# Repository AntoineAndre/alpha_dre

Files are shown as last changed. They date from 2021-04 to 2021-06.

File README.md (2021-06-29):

# &#945;. Dré

__Or "How to fit an ISO layout in a 40% keyboard ?"__

## Table of contents
- [Presentation](#Presentation)
- [Layout](#Layout)
- [Case](#Case), more details [here](case/case_doc.md)
- [PCB](#PCB), more details [here](pcb/pcb_doc.md)
- [Parts](#Parts)
- [Results](#Results)
- [Renders](#Renders), more details [here](renders/renders_doc.md)

## Presentation

This project started as a need to find a **new mechanical keyboard with a french ISO layout support**. It also aims to keep a minimalist design that we can find on most 40% keyboards. It will therefore include all the 3D CAD files and various pcb related files to conduct the project along with a documentation to build the keyboard.

This keyboard is __Via and Vial compatible__ to give a better user experience (especially when it comes to remapping keys).

pic_both_keeb

__All pictures of this project can be found [here](https://flic.kr/s/aHsmVLZSPn)__ (acrylic case) __and [here](https://flic.kr/s/aHsmVCqc8F)__ (no plate tray mount)

### Layout

The keyboard presents 42 keys that are placed in an ISO layout, and even if the layout seems odd, most of keycaps set will fit this design. With juste 3 layers the keyboard becomes fully usable as shown in the firmware part.

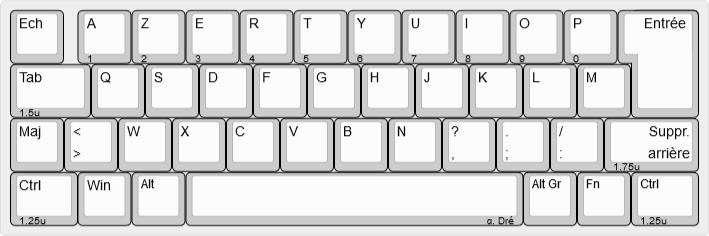
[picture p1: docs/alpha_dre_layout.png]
alpha_dre_layout


### Case

#### 3D printed version

A top mounted case aimed to be 3D printed has been done to complete the build.

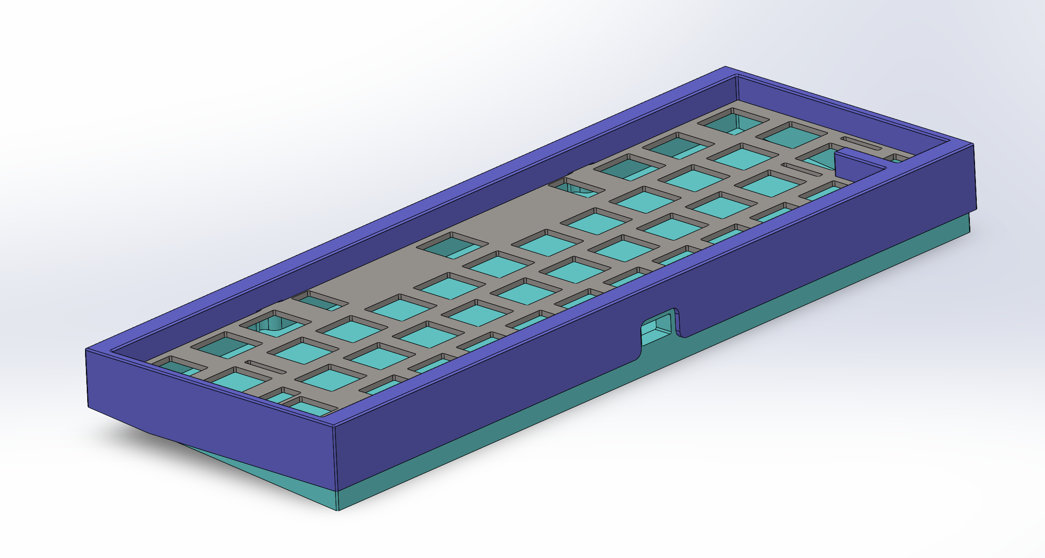
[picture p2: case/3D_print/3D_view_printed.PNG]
case_3D_view


Blueprints are available in dedicated folder, short link to pdf blueprints :
- [global assembly](https://raw.githubusercontent.com/antoineandre/alpha_dre/main/case/3D_print/assembly_blueprint.pdf)
- [top part](https://raw.githubusercontent.com/antoineandre/alpha_dre/main/case/3D_print/bottom_part_blueprint.pdf)
- [bottom part](https://raw.githubusercontent.com/antoineandre/alpha_dre/main/case/3D_print/top_part_blueprint.pdf)

#### Acrylic stack
The case is a *high profile* one (meaning the electronic parts and switches are hidden by the case) and has been designed to be manufactured with only laser cut acrylic plates of various sizes. These plates are fixed with M2 screws (M2x16) and are hidden with rubber bumps on the bottom of the case. This conception leads to a *sandwich mount* keyboard.

In order to give the keyboard a little angle for typing, two different feet have been design to be screwed at the back of the case.

A last option of low profile (barely no case) is available and needs practically no manufacturing. This option leads to a *tray mount* keyboard with no plate (this is the chosen option shown in the beginning of this presentation).

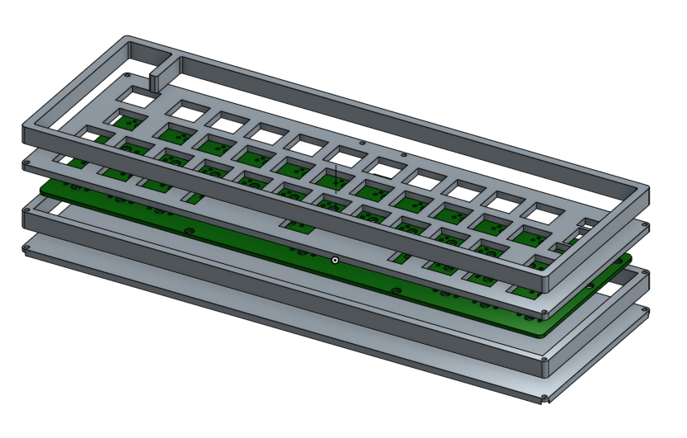
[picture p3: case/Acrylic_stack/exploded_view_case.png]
case_top_view


*Side note on the acrylic case : the design was a bit too lose and the gap between keycaps and top layer of the case can be reduced. Furthermore the plate was designed to host plate mounted stabilizers, but the pcb was designed for pcb mounted stabs...*

### PCB

The pcb has been designed with Kicad software and gerbers files are available in the dedicated folder. This pcb hosts an Atmega32U4-AU for the keyboard control and is (as for other electronic components) soldered in surface. 

pic_pcb

More on the pcb design available in the documentation file.

### Parts

Here is a global list of all parts needed to perform this keyboard build:

- [ ] Laser cut acrylic plates
- [ ] Screws (M2 for sandwich mount and M3 for skeleton mount)
- [ ] SMD components fot the pcb (see the pcb documentation for more details)
- [ ] pcb plate
- [ ] 42 switches
- [ ] 6.25u and 2u stabilizers
- [ ] ISO keycap set
- [ ] Soldering tools
- [ ] Drill and threading tools

<!-- ## Documents

- [case documentation](case/case_doc.md)
- [pcb documentation](pcb/pcb_doc.md)
- [firmware documentation](firmware/alpha_dre/readme.md) -->

### Results

A first prototype with a simple skeleton case made out of plexiglass have been made to validate that the keyboard was responding correctly to the firmware and was usable. More on the cases will be done in the future (notably with the cut acrylic plates for the sandwich mount and with a 3d printed case).

pic_side

Second prototype was made with acrylic sandwich plates (as intended in the original project). Two pictures showing the results of this case can be seen below.

pic_acrylic

pic_acrylic_2

### Renders

A bunch of renders have been made to validate the overall looking of the keyboard.

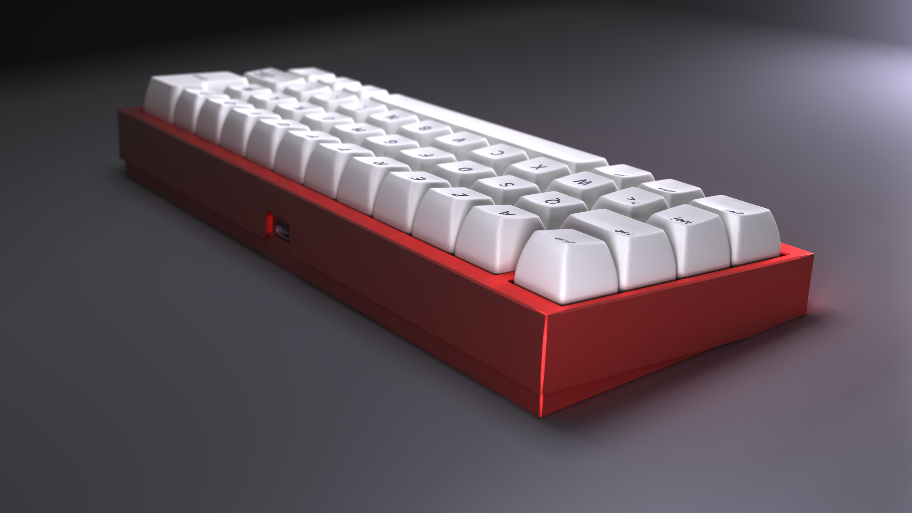
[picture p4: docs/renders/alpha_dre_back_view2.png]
alpha_dre_render


__Complete set of renders__ can be found __[here](docs/renders/renders_doc.md)__

## Aknowledgment

- [Masterzen "Designing a keyboard from scratch" guide](https://www.masterzen.fr/2020/05/03/designing-a-keyboard-part-1/)
- [French mechanical keyboard community](https://github.com/mkbdfr) for their help, feedback and amelioration propositions to make this design as "usable" as possible.

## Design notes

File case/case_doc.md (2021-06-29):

# Case conception and build

## 3D printed case Rev2

Render_view

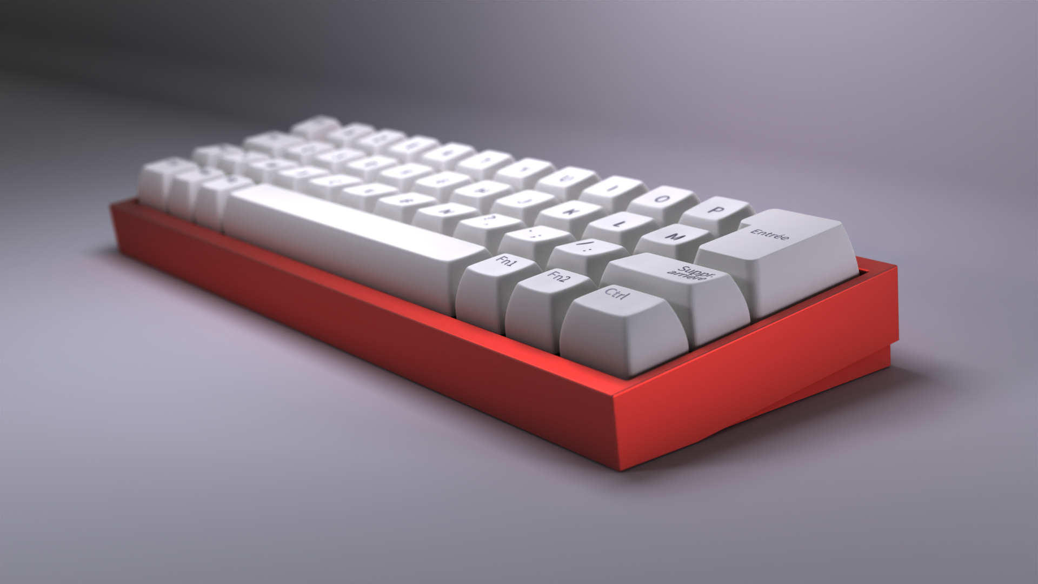
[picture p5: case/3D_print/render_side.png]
Render_view


Blueprints are available here as pdf:
- [assembly scheme](https://github.com/AntoineAndre/alpha_dre/raw/main/case/3D_print/assembly_blueprint.pdf)
- [top part scheme](https://github.com/AntoineAndre/alpha_dre/raw/main/case/3D_print/top_part_blueprint.pdf)
- [top part scheme](https://github.com/AntoineAndre/alpha_dre/raw/main/case/3D_print/bottom_part_blueprint.pdf)

## Acrylic case Rev1

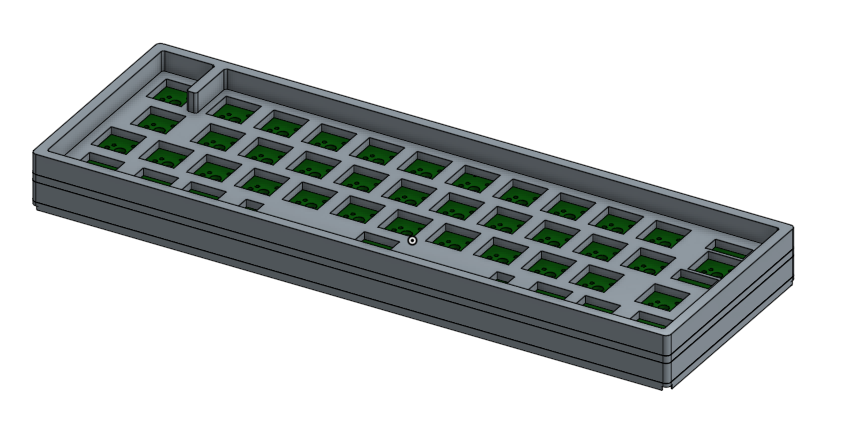
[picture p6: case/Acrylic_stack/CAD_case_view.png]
CAD_view


CAD_view

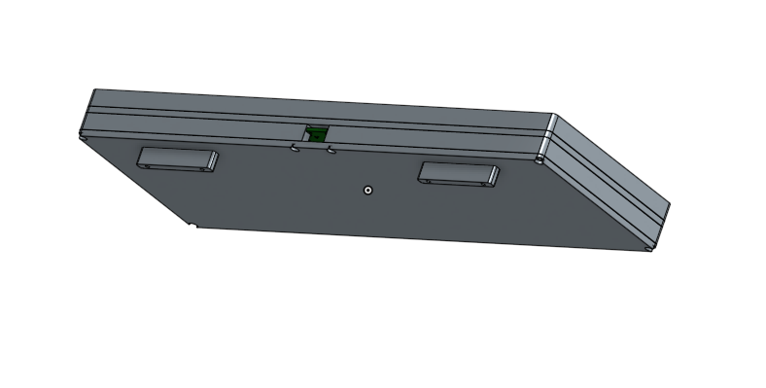
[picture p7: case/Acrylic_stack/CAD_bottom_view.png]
CAD_view


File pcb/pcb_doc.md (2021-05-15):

# Alpha. Dré PCB documentation

## Main design

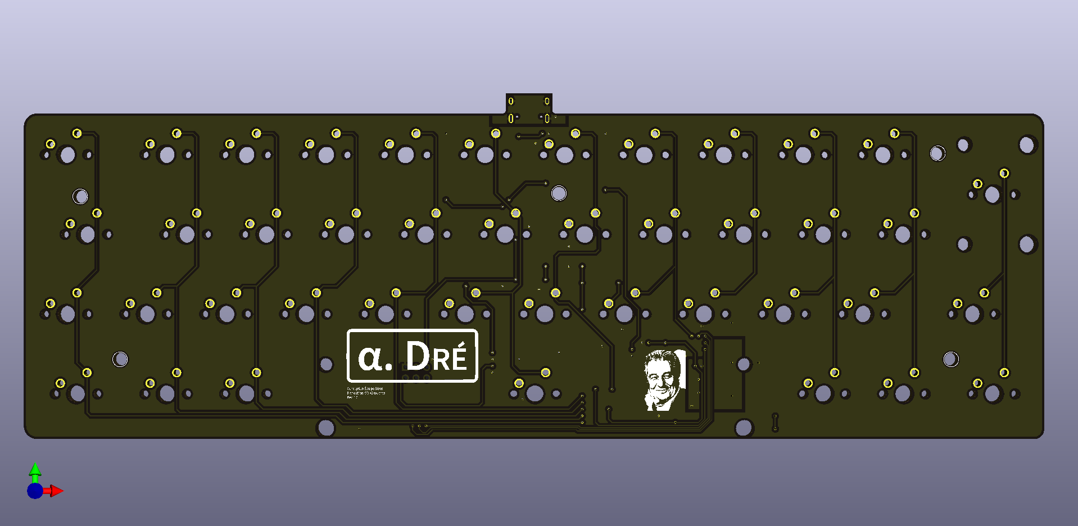
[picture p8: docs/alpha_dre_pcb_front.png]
front view


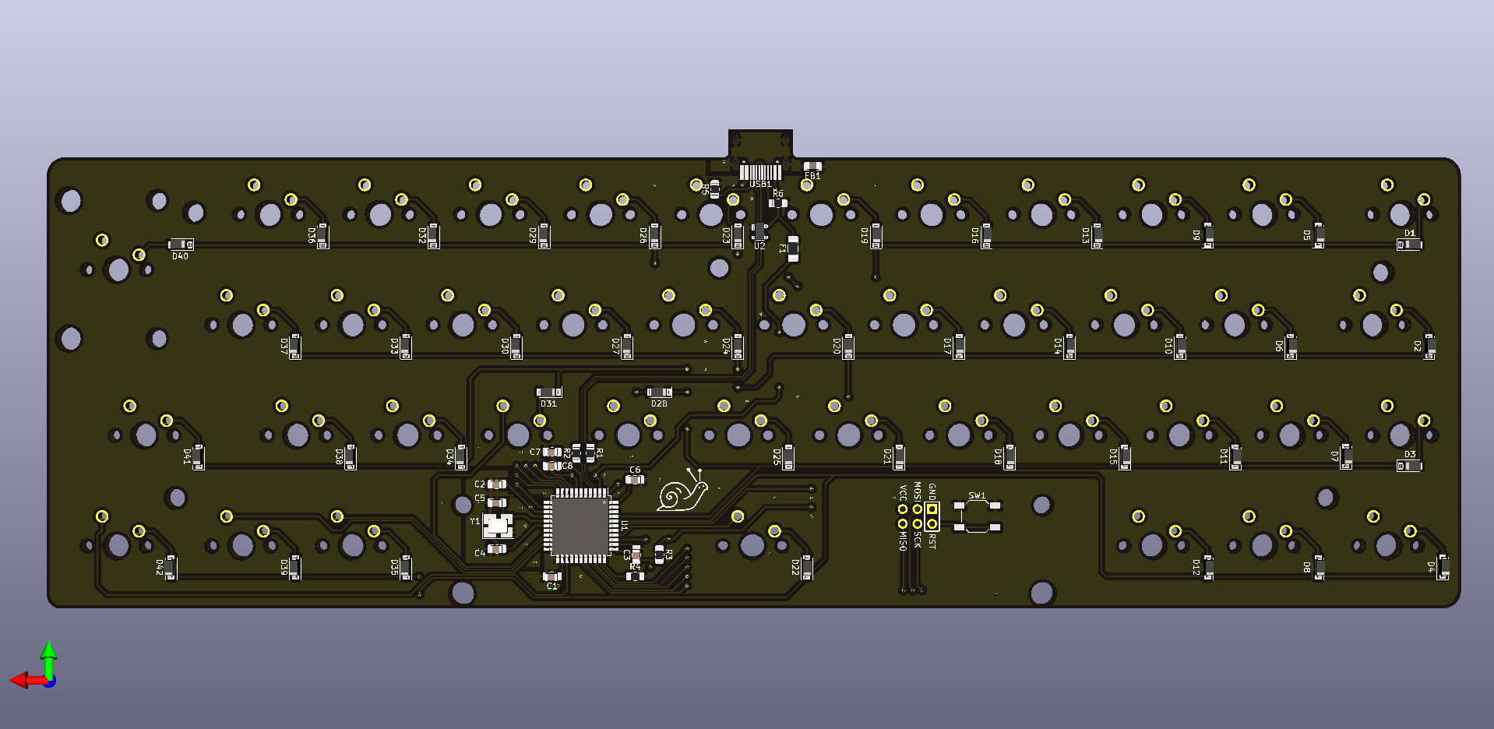
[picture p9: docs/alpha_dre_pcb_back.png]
back view


Even if the design is planed to be sandwich mounted with a stack of acrylic plate, the PCB design offers the possibily to go for a trail mount with dedicated M3 holes (5 evenly spaced on the PCB).

## Part list

The PCB has been designed to be soldered with SMD components and therefore needs a lot of different electronic parts that are listed below:

|Designation|Type |Footprint |Quantity|
|---|---|---|---|
|FB1 |Ferrite bead |805 |1 |
|USB1 |USB connector |HRO-TYPE-C-31-M-12|1 |
|U2 |PRTR5V0U2X |SOT143B |1 |
|SW1 |Reset switch |SKQG |1 |
|R6,R5 |5.1 kOhm resistor|805 |2 |
|R4,R3 |10 kOhm resistor |805 |2 |
|R2,R1 |22 Ohm resistor  |805 |2 |
|C8,C3,C2,C1|100 nF capacitor |805 |4 |
|Y1 |16 MHz crystal |3225 |1 |
|U1 |Atmega 32U4-AU |TQFP-44 |1 |
|F1 |PTC Fuse |1206 |1 |
|C7 |1 uF capacitor |805 |1 |
|C6 |10 uF capacitor  |805 |1 |
|C5,C4 |22 pF capacitor  |805 |2 |
|D1-42 |Diode |SOD-123 |42 |

## Results

After soldering the PCB with all above listed parts the results shooted with a macro lense looks as follow :

pic_pcb

pic_pcb_2

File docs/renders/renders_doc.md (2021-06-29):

# Renders of &#945;. Dré keyboard

alpha_dre_render0

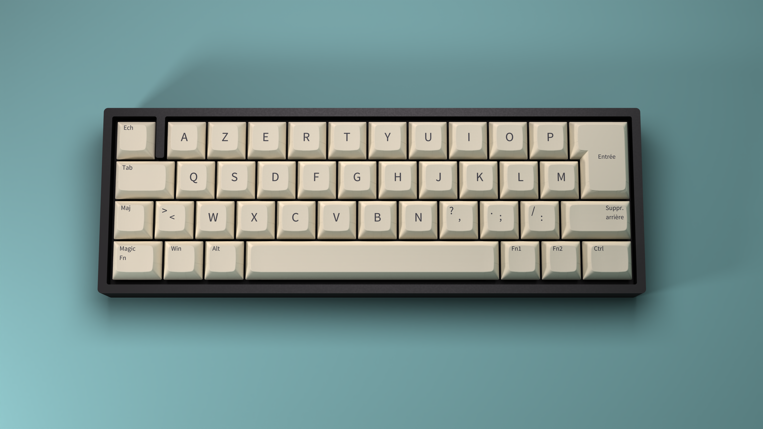
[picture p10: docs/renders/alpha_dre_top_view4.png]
alpha_dre_render1


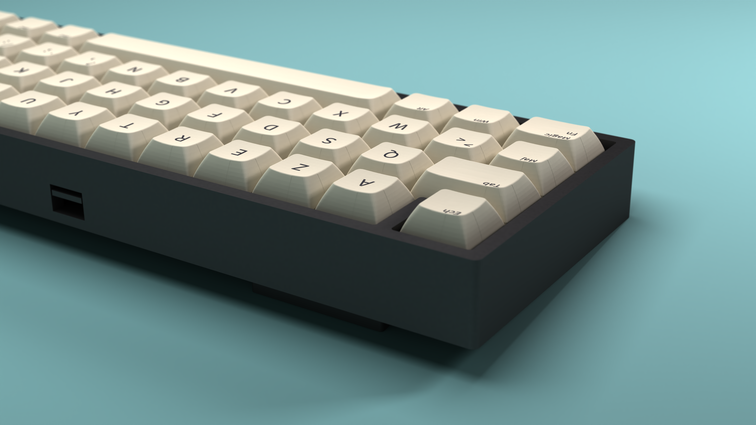
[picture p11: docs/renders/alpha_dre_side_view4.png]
alpha_dre_render2


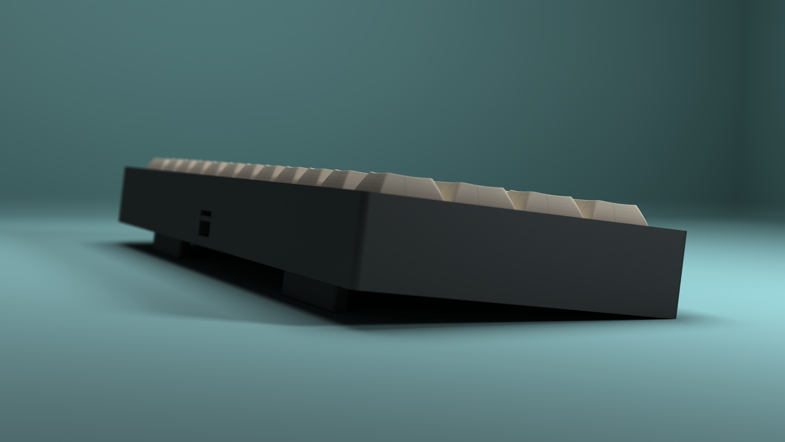
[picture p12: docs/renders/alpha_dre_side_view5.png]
alpha_dre_render3


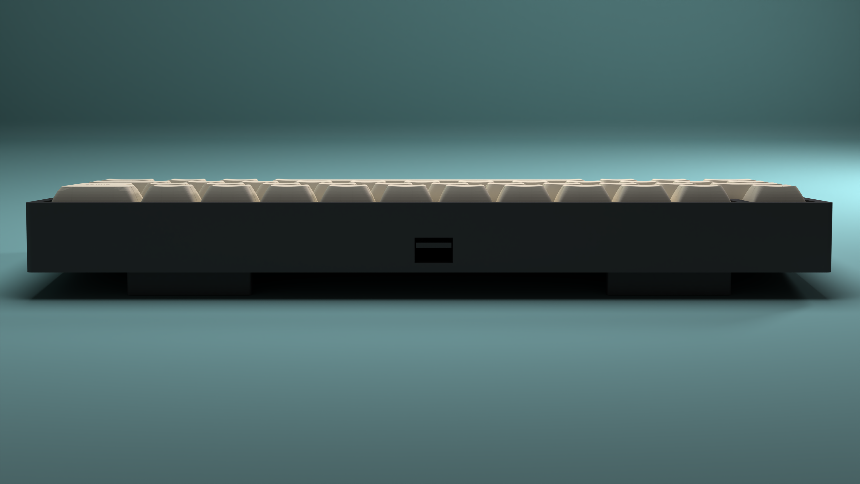
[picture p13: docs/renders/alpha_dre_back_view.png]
alpha_dre_render4


alpha_dre_render5

alpha_dre_render6

alpha_dre_render7

alpha_dre_render8

alpha_dre_render9

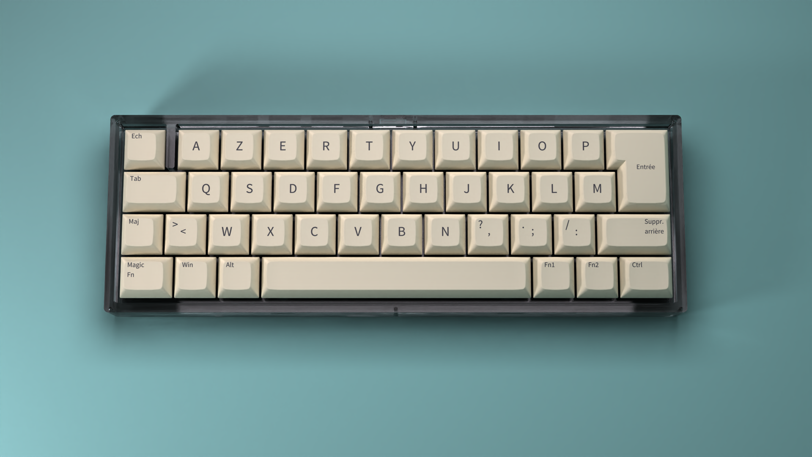
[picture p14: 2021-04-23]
docs/renders/alpha_dre_top_view3.png

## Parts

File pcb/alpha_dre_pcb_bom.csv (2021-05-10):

Id | Designator | Package | Quantity | Designation | Soldered ?
11 | FB1 | L_0805_2012Metric_Pad1.15x1.40mm_HandSolder | 1 | Ferrite_Bead_Small
12 | USB1 | HRO-TYPE-C-31-M-12-HandSoldering | 1 | HRO-TYPE-C-31-M-12
13 | U2 | SOT143B | 1 | PRTR5V0U2X
14 | SW1 | SW_SPST_SKQG_WithStem | 1 | SW_Push
15 | R6,R5 | R_0805_2012Metric_Pad1.20x1.40mm_HandSolder | 2 | 5.1k
16 | R4,R3 | R_0805_2012Metric_Pad1.20x1.40mm_HandSolder | 2 | 10k
17 | R2,R1 | R_0805_2012Metric_Pad1.20x1.40mm_HandSolder | 2 | 22
18 | J1 | Reset_Pretty-Mask | 1 | AVR-ISP-6
19 | C8,C3,C2,C1 | C_0805_2012Metric_Pad1.18x1.45mm_HandSolder | 4 | 0.1uF
20 | Y1 | Crystal_SMD_3225-4Pin_3.2x2.5mm_HandSoldering | 1 | 16MHz
21 | U1 | TQFP-44_10x10mm_P0.8mm | 1 | ATmega32U4-AU
22 | F1 | Fuse_1206_3216Metric_Pad1.42x1.75mm_HandSolder | 1 | 500mA
23 | C7 | C_0805_2012Metric_Pad1.18x1.45mm_HandSolder | 1 | 1uF
24 | C6 | C_0805_2012Metric_Pad1.18x1.45mm_HandSolder | 1 | 10uF
25 | C5,C4 | C_0805_2012Metric_Pad1.18x1.45mm_HandSolder | 2 | 22pF
26 | D42,D41,D40,D39,D38,D37,D36,D35,D34,D33,D32,D31,D30,D29,D28,D27,D26,D25,D24,D23,D22,D21,D20,D19,D18,D17,D16,D15,D14,D13,D12,D11,D10,D9,D8,D7,D6,D5,D4,D3,D2,D1 | D_SOD-123-Pretty | 42 | D_Small

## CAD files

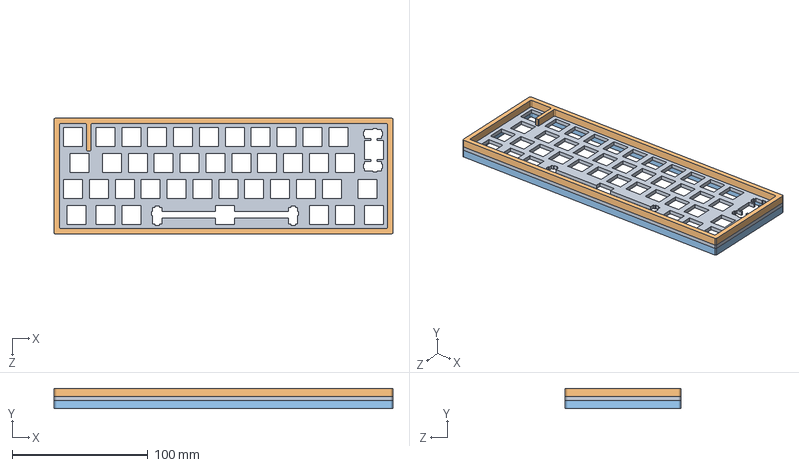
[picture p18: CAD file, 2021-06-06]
case/Rev2/solidworks_project/acry_assembly.SLDASM
249.6 x 15.0 x 85.2 mm
switch_plate
top_plate
mid_plate

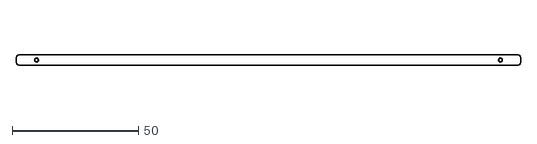
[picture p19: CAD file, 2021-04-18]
case/Acrylic_stack/Acrylic_files/case_foot_option_line.dxf
200.0 x 4.00

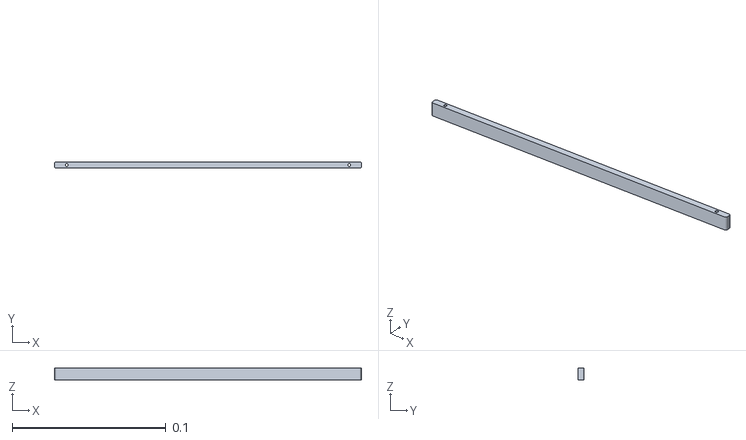
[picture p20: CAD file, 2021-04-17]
case/Acrylic_stack/STL/angle_support.stl
0.2 x 0.004 x 0.008

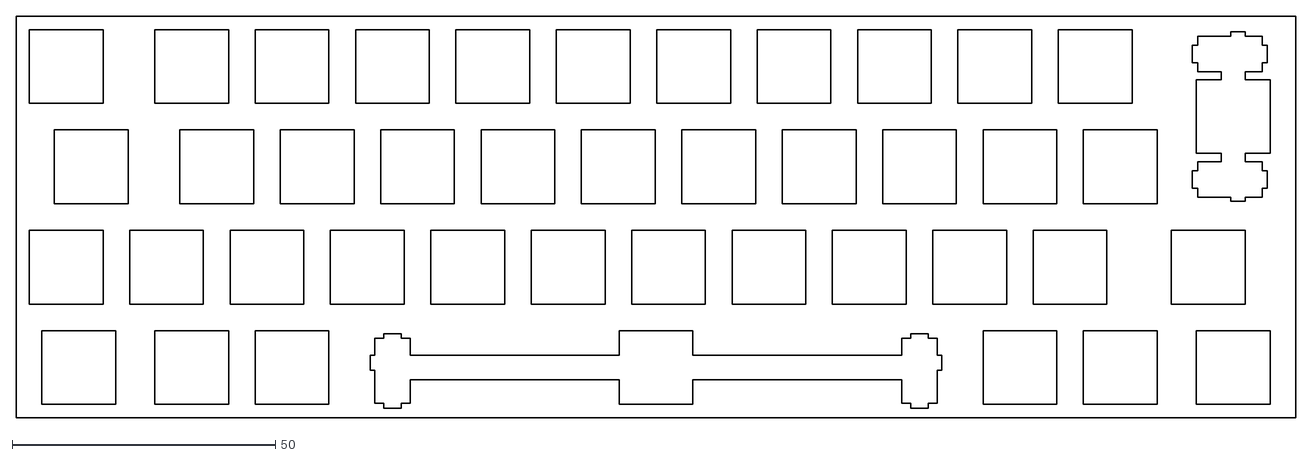
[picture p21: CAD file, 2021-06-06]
case/Rev2/generated_plate.dxf
242.9 x 76.2

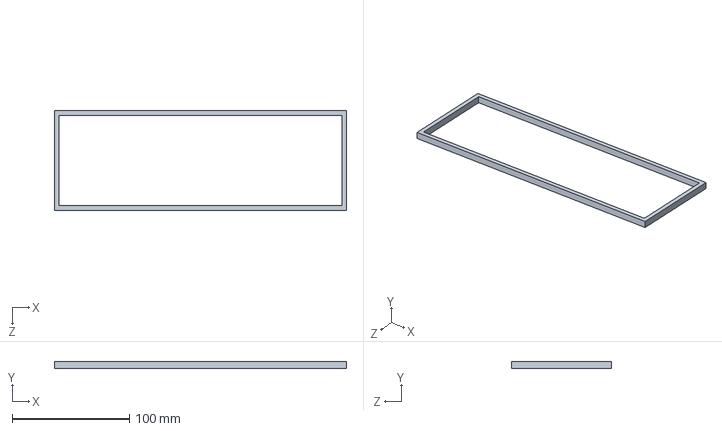
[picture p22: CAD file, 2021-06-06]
case/Rev2/solidworks_project/mid_plate.SLDPRT
249.6 x 6.00 x 85.2 mm

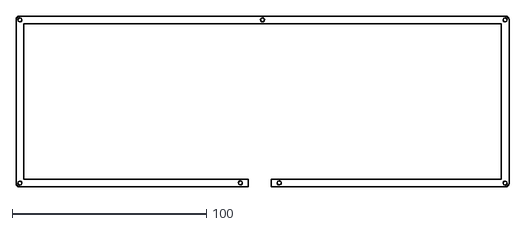
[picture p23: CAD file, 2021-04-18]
case/Acrylic_stack/Acrylic_files/case_mid_line.dxf
254.1 x 88.1

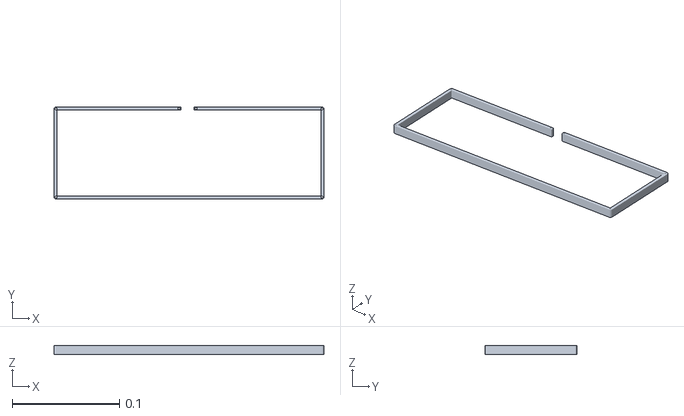
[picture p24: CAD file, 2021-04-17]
case/Acrylic_stack/STL/mid.stl
0.252 x 0.086 x 0.008

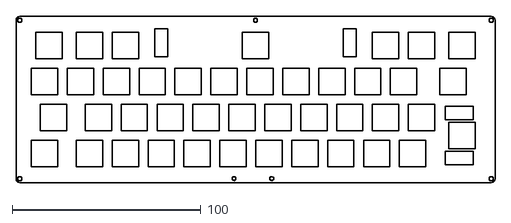
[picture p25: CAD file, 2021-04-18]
case/Acrylic_stack/Acrylic_files/case_plate_line.dxf
254.1 x 88.1

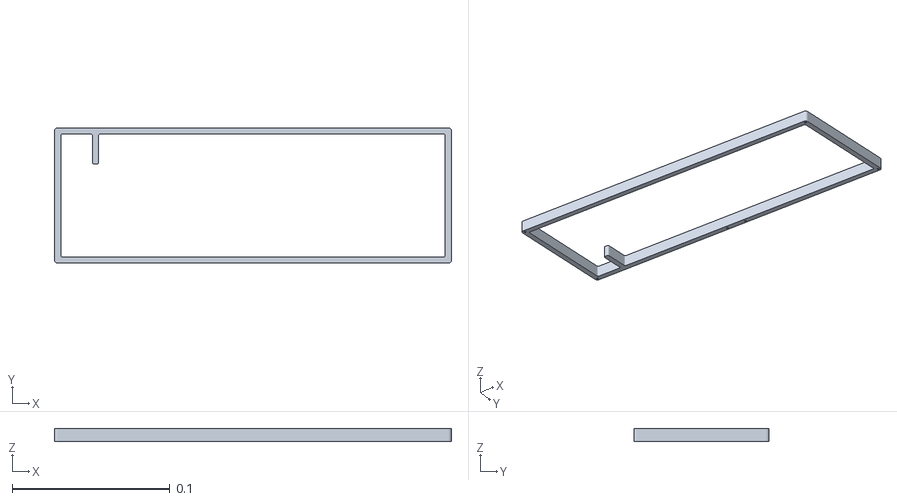
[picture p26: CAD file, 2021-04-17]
case/Acrylic_stack/STL/top.stl
0.252 x 0.086 x 0.008

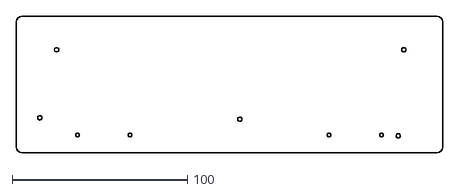
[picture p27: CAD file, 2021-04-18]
case/Acrylic_stack/Acrylic_files/case_bottom_alone_line.dxf
243.7 x 77.8

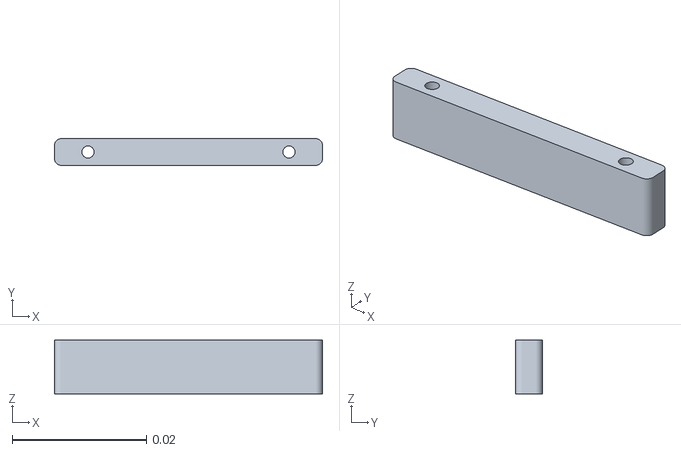
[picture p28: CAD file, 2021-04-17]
case/Acrylic_stack/STL/small_angle_support.stl
0.04 x 0.004 x 0.008

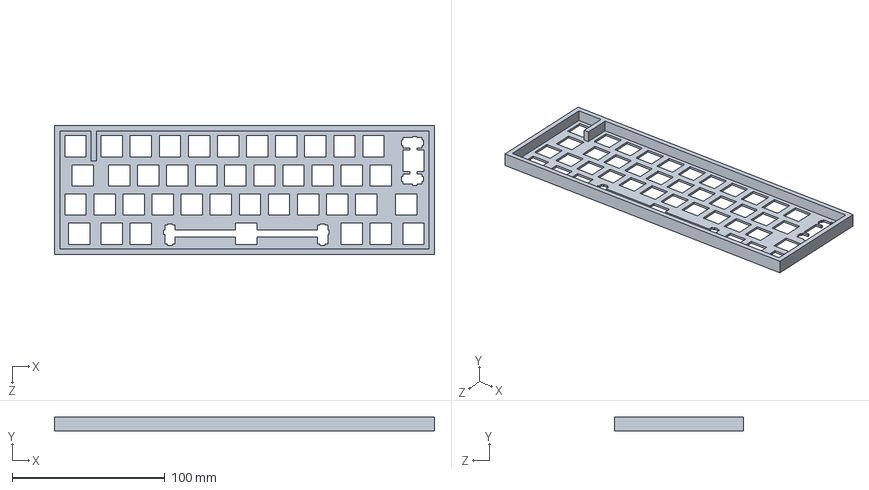
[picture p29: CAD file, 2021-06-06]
case/Rev2/solidworks_project/top_plate_integrated.SLDPRT
249.0 x 9.50 x 84.7 mm

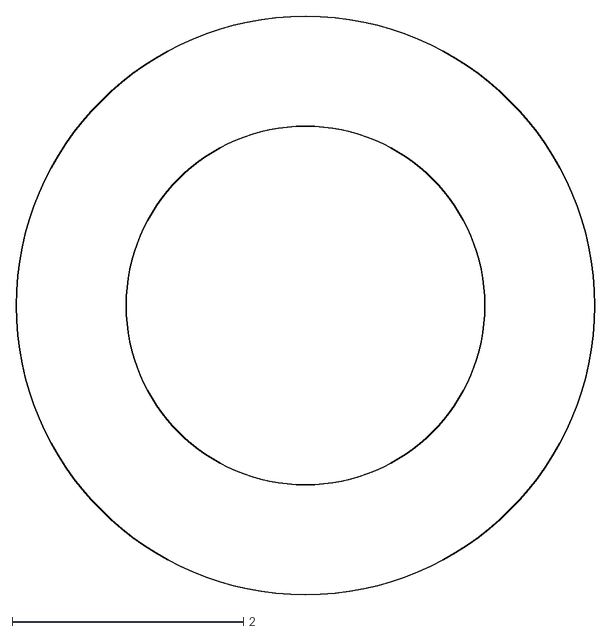
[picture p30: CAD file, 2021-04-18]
case/Acrylic_stack/Acrylic_files/case_circ_stand_line.dxf
5.00 x 5.00

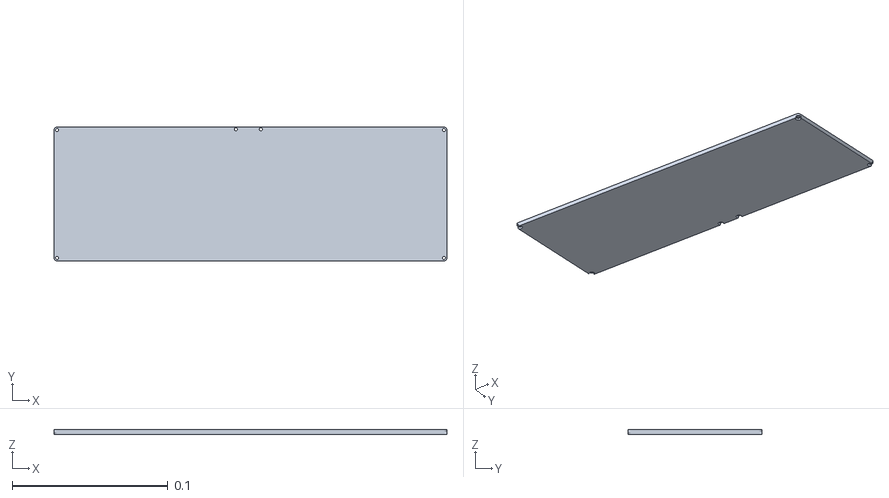
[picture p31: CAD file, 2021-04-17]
case/Acrylic_stack/STL/bottom.stl
0.252 x 0.086 x 0.003

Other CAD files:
case/Rev2/solidworks_project/top_plate.SLDPRT
case/Rev2/solidworks_project/switch_plate.SLDPRT
case/Acrylic_stack/Acrylic_files/case_foot_line.dxf
case/Acrylic_stack/STL/plate.stl
case/Acrylic_stack/Acrylic_files/case_bottom_line.dxf
case/Acrylic_stack/Acrylic_files/case_top_line.dxf

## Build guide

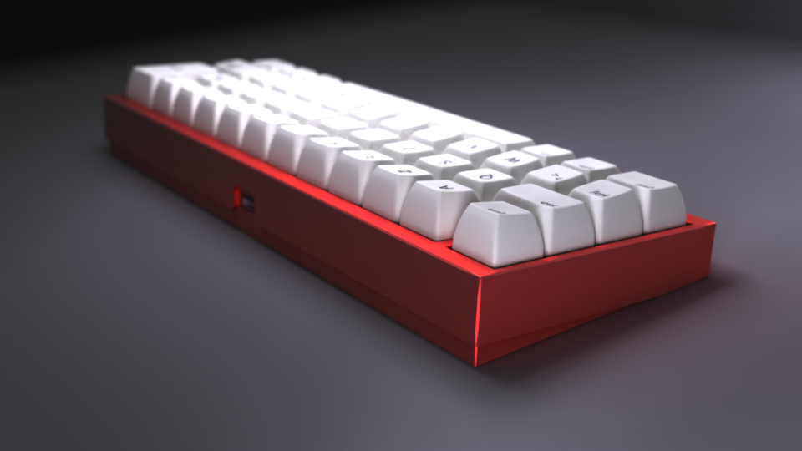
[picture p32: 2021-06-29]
case/3D_print/render_back.png

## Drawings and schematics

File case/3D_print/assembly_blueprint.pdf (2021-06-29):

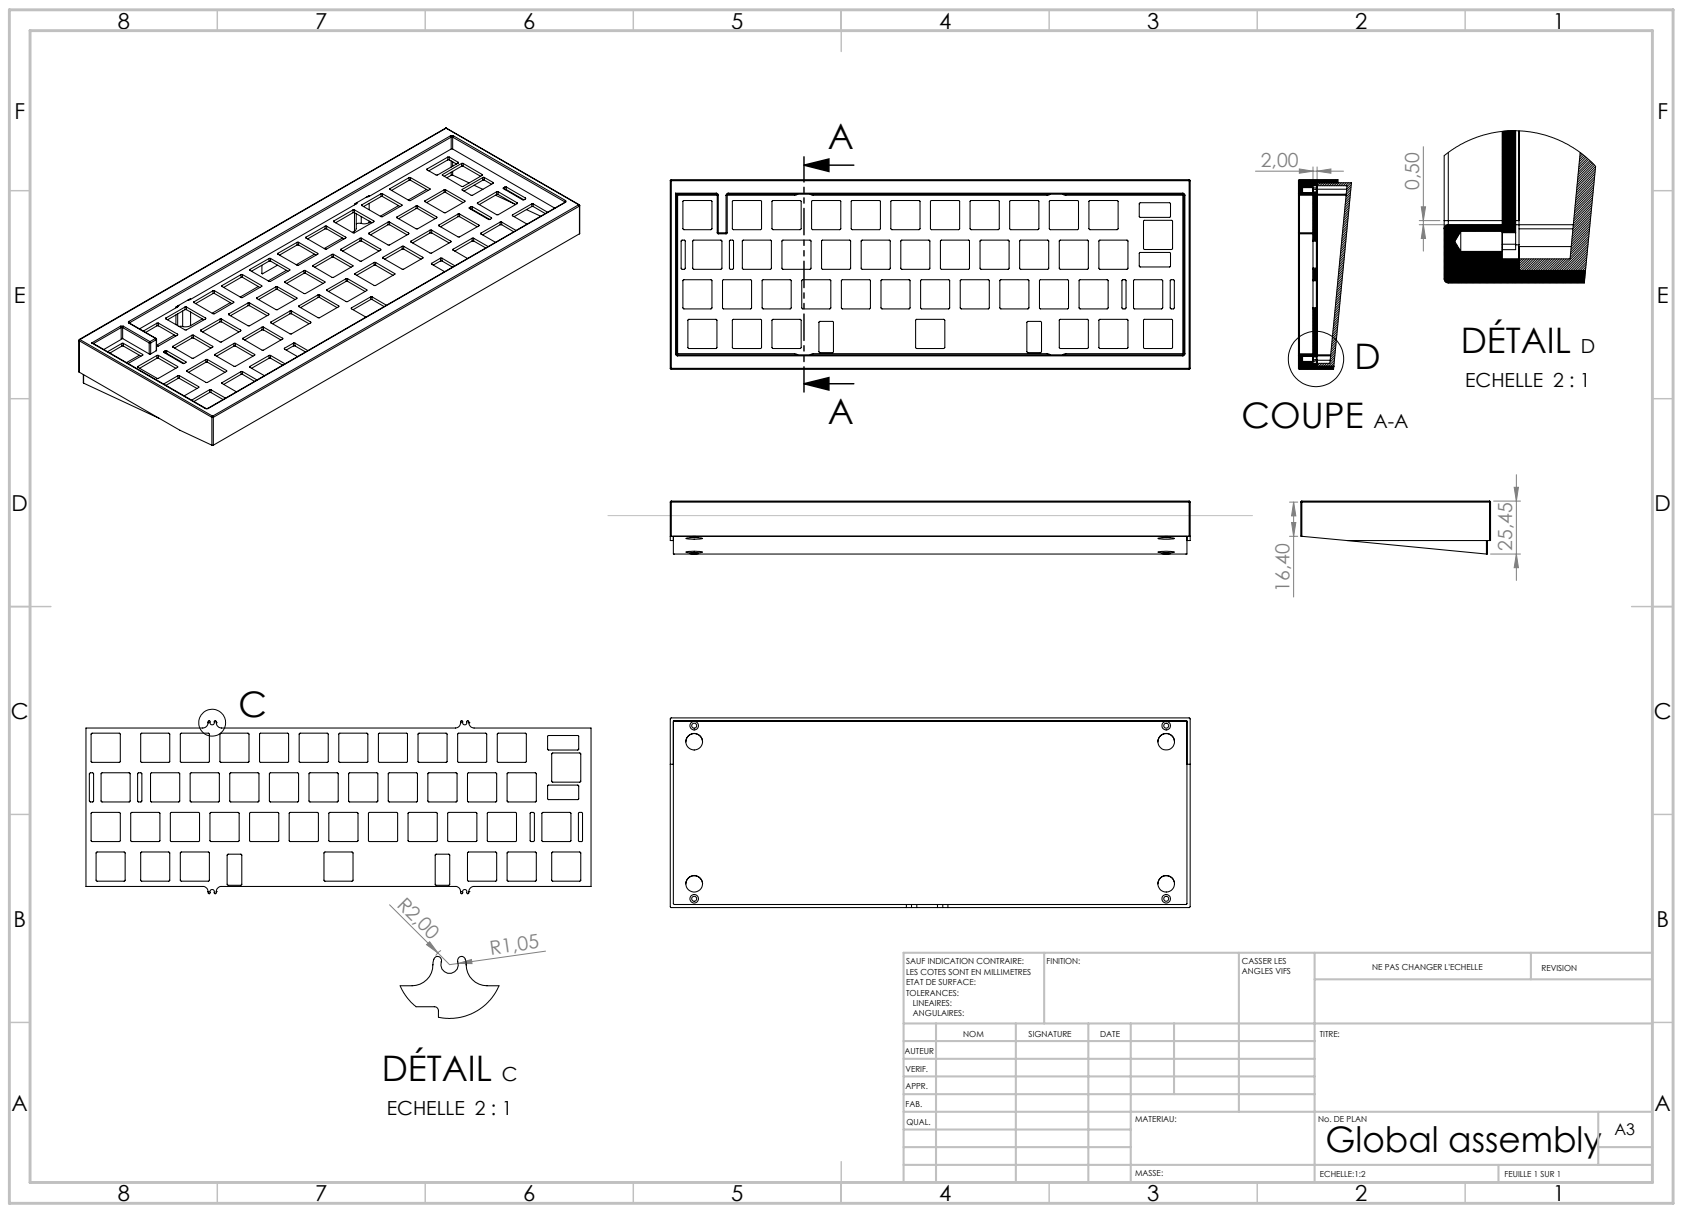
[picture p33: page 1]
COUPE A-A; DÉTAIL C; ECHELLE 2 : 1; DÉTAIL D; FINITION:; CASSER LES; ANGLES VIFS; NE PAS CHANGER L'ECHELLE; REVISION; ECHELLE:1:2; FEUILLE 1 SUR 1

SAUF INDICATION CONTRAIRE:
LES COTES SONT EN MILLIMETRES
ETAT DE SURFACE:
TOLERANCES:
LINEAIRES:
ANGULAIRES:

NOM | SIGNATURE | DATE | | | | TITRE:

AUTEUR
VERIF.
APPR.
FAB.
QUAL. | | | | MATERIAU: | No. DE PLAN Global assembly | A3

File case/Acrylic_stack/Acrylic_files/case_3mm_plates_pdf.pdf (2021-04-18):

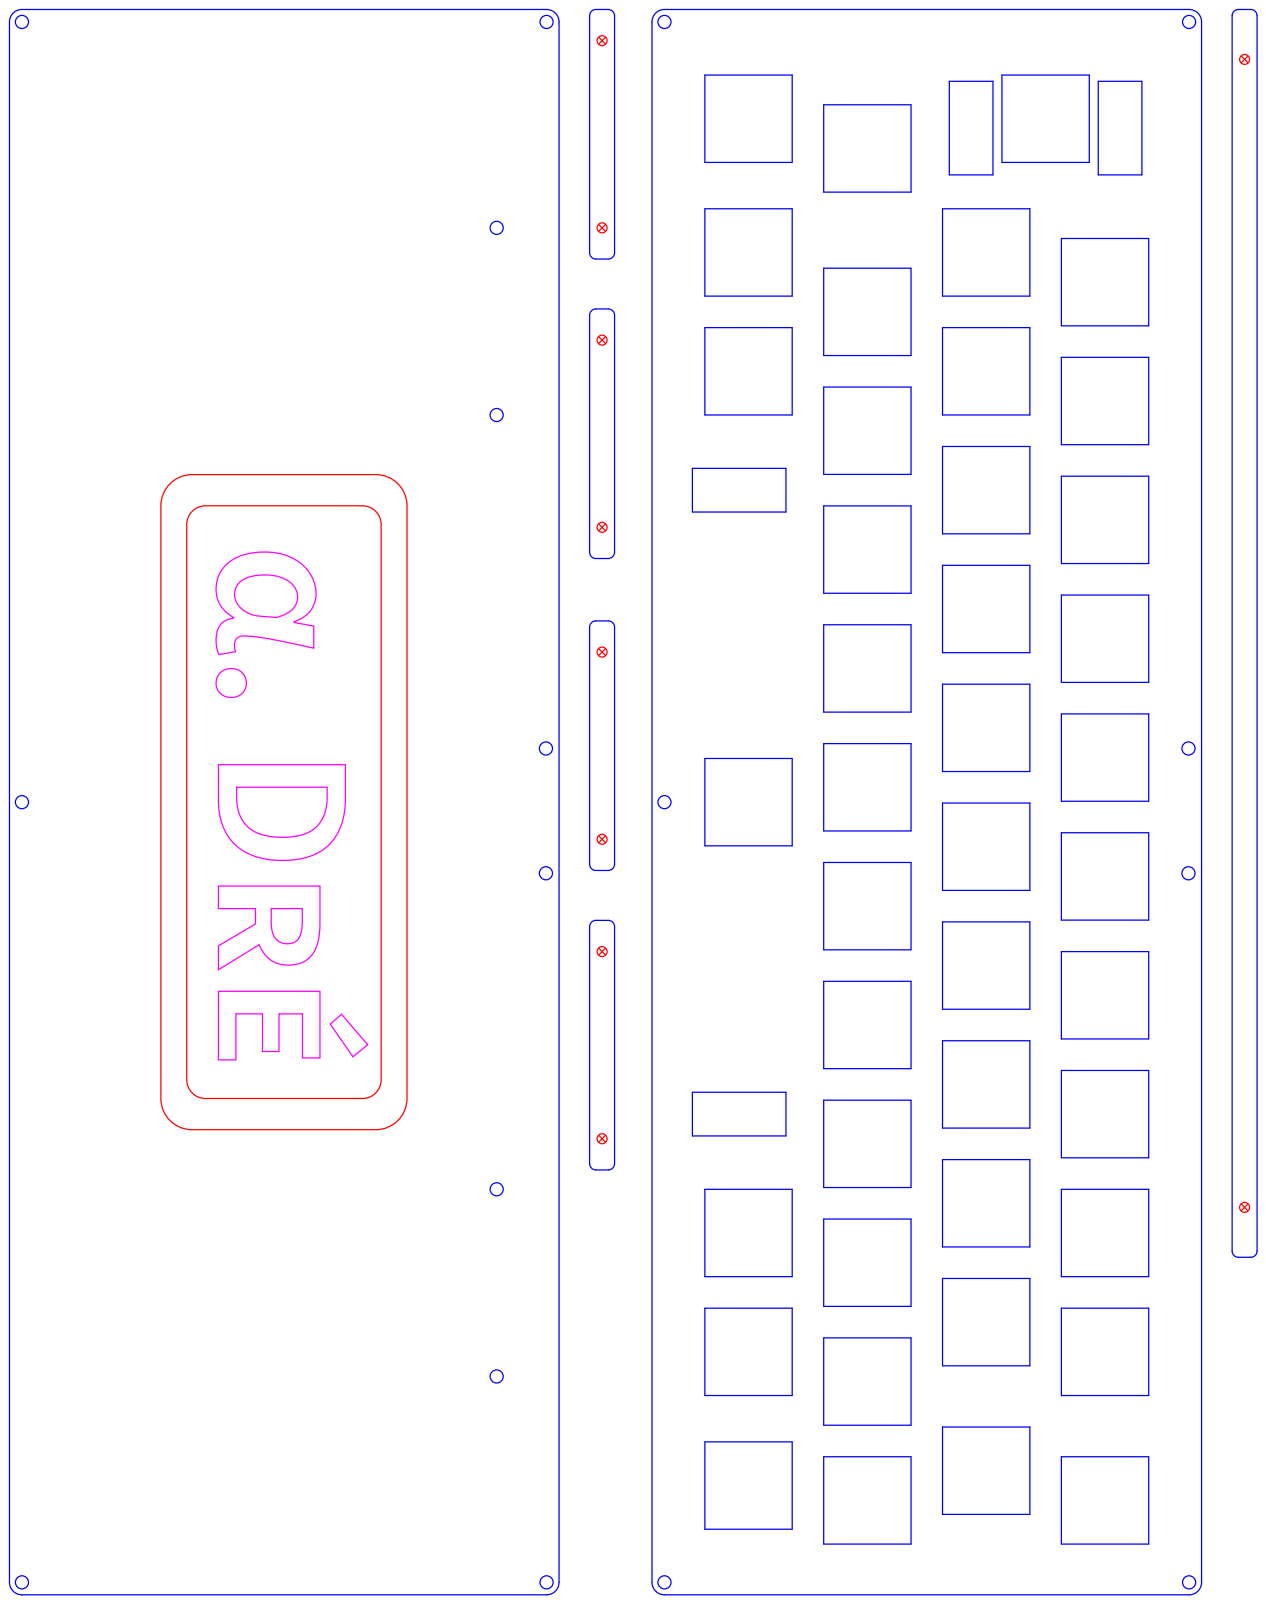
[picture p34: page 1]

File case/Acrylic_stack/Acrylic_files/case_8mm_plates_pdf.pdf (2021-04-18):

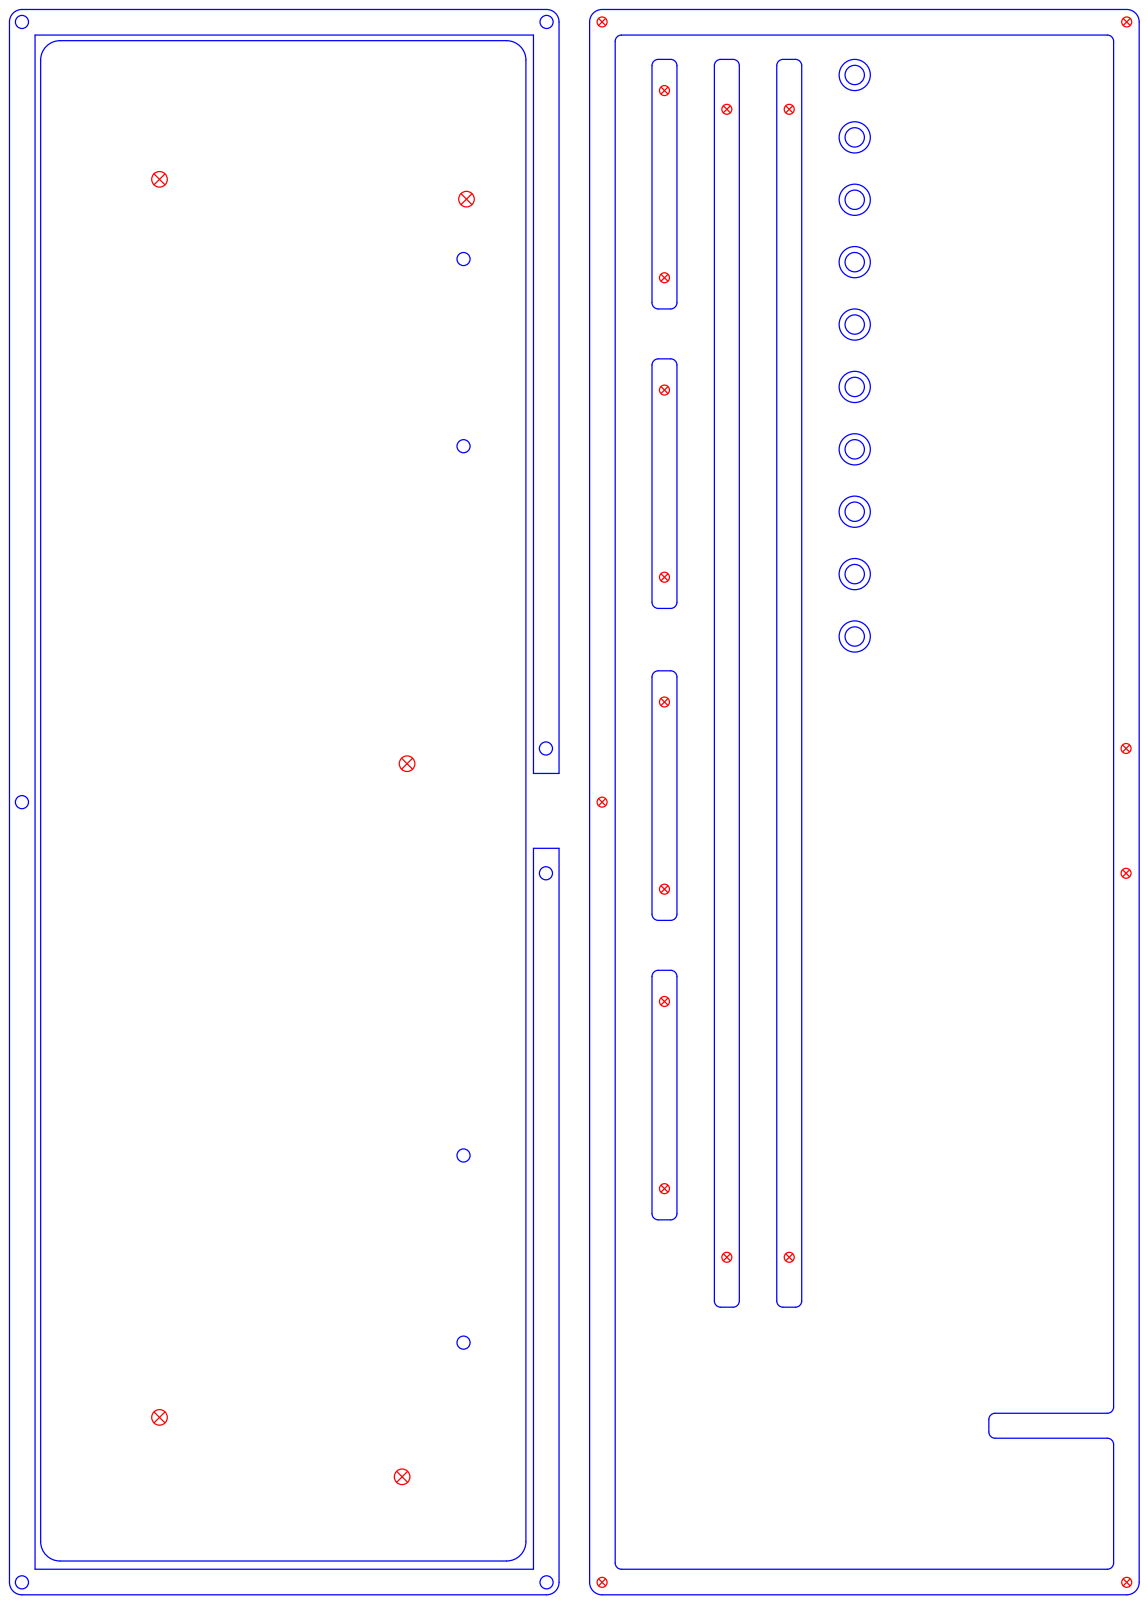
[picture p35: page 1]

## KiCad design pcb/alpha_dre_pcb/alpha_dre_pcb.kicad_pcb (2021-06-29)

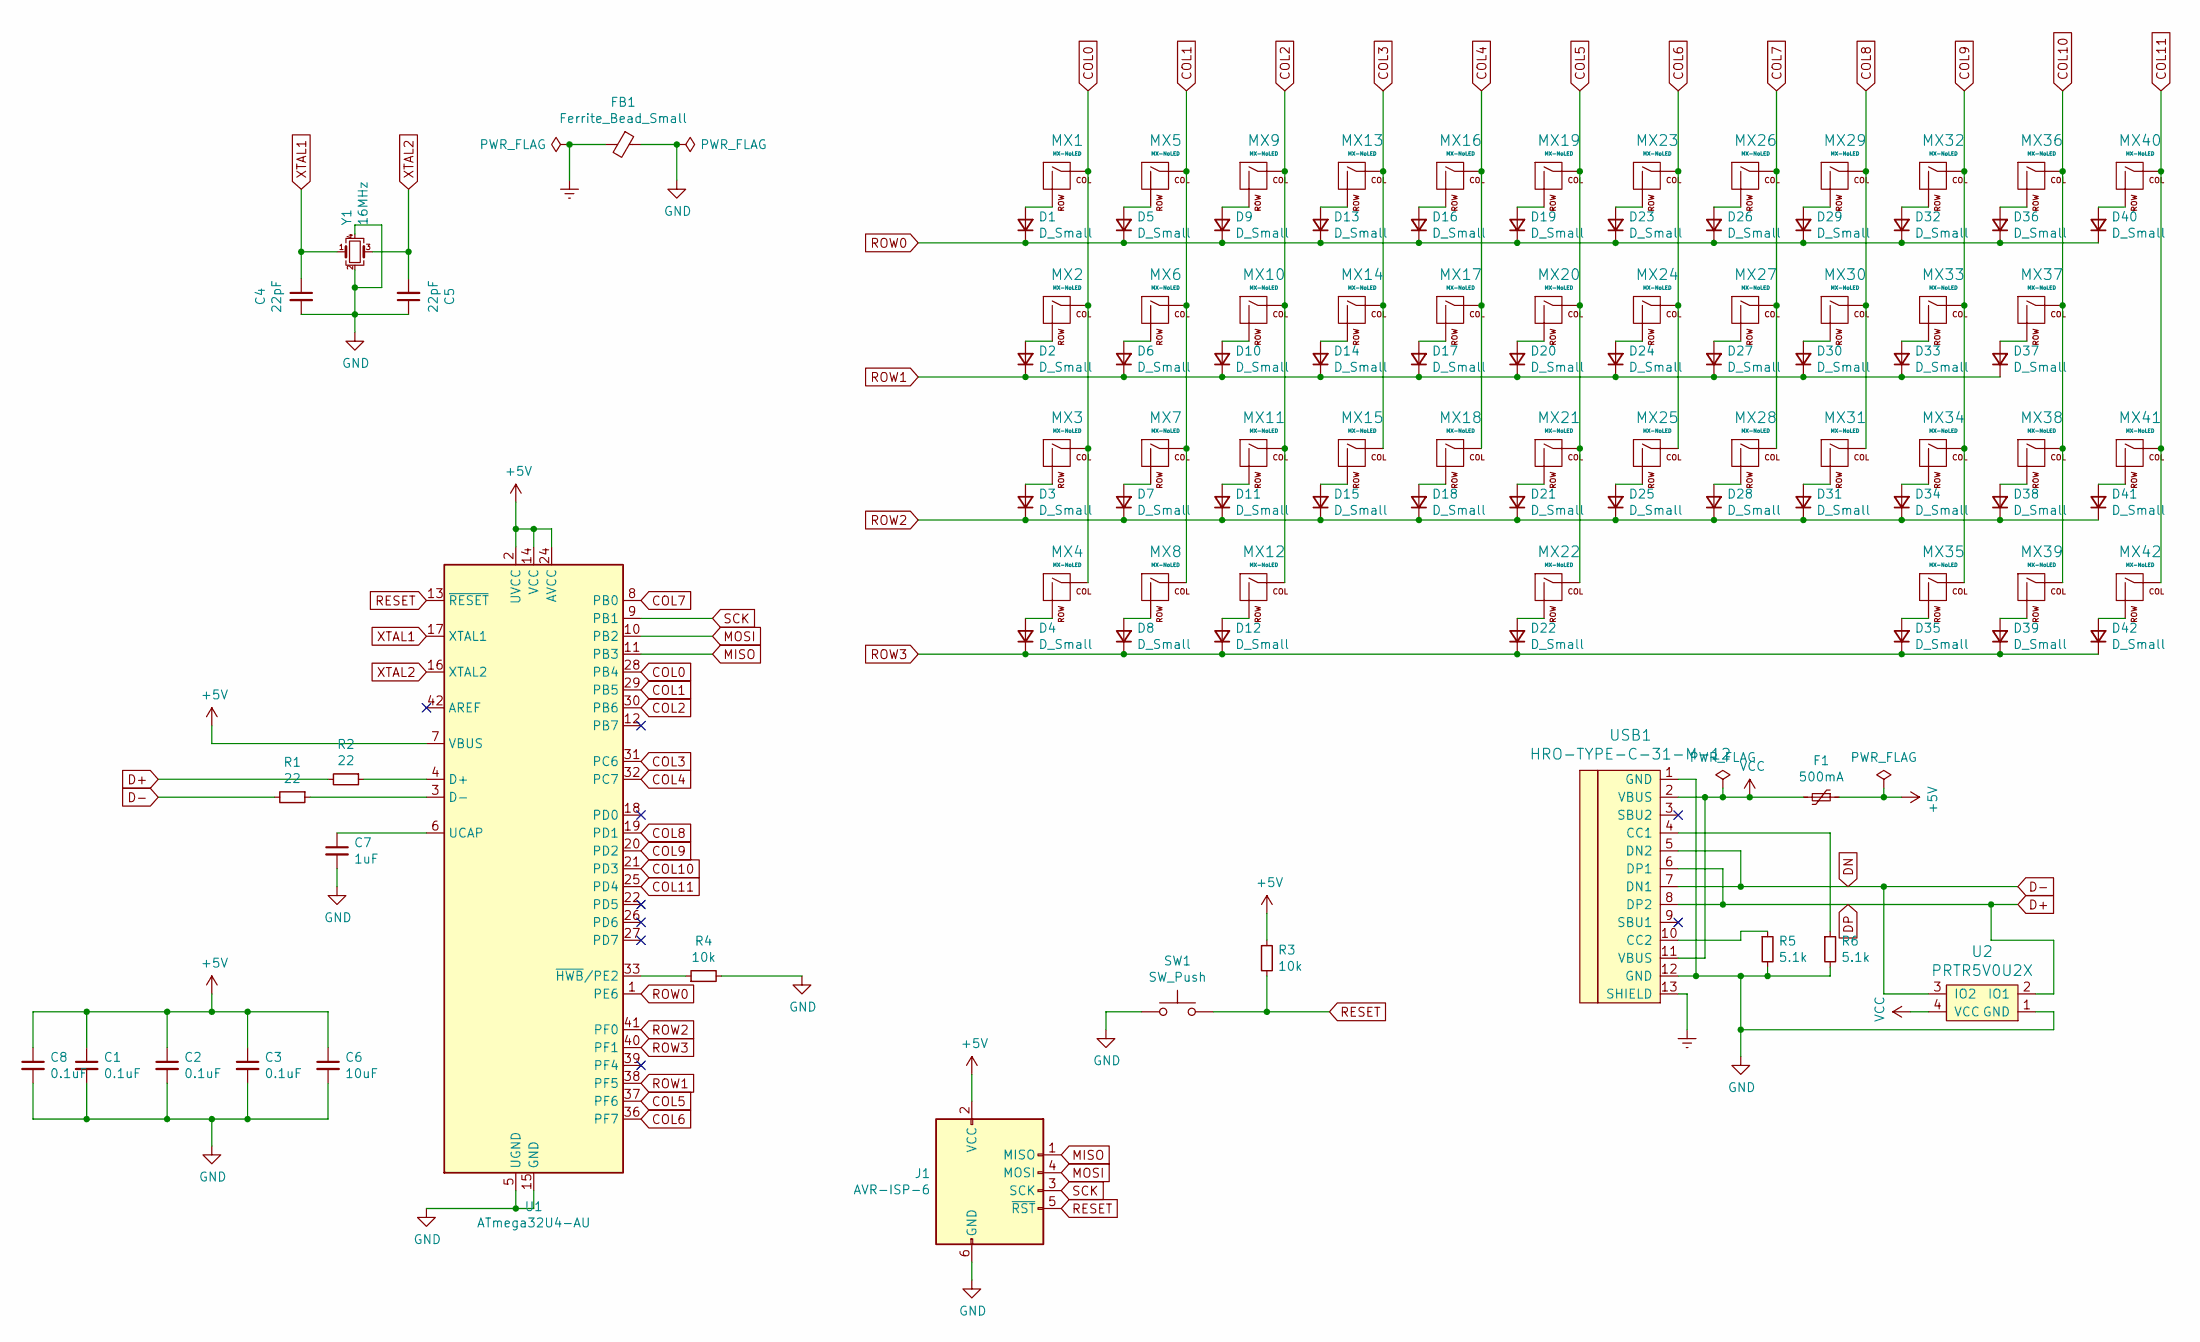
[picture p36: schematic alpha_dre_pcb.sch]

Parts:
C1, C2, C3, C8: 0.1uF; C_0805_2012Metric_Pad1.18x1.45mm_HandSolder
C4, C5: 22pF; C_0805_2012Metric_Pad1.18x1.45mm_HandSolder
C6: 10uF; C_0805_2012Metric_Pad1.18x1.45mm_HandSolder
C7: 1uF; C_0805_2012Metric_Pad1.18x1.45mm_HandSolder
D1, D2, D3, D4, D5, D6, D7, D8, D9, D10, D11, D12, D13, D14, D15, D16, D17, D18, D19, D20, D21, D22, D23, D24, D25, D26, D27, D28, D29, D30, D31, D32, D33, D34, D35, D36, D37, D38, D39, D40, D41, D42: D_Small; D_SOD-123-Pretty
F1: 500mA; Fuse_1206_3216Metric_Pad1.42x1.75mm_HandSolder
FB1: Ferrite_Bead_Small; L_0805_2012Metric_Pad1.15x1.40mm_HandSolder
J1: AVR-ISP-6; Reset_Pretty-Mask
MX1, MX3, MX5, MX6, MX7, MX8, MX9, MX10, MX11, MX12, MX13, MX14, MX15, MX16, MX17, MX18, MX19, MX20, MX21, MX23, MX24, MX25, MX26, MX27, MX28, MX29, MX30, MX31, MX32, MX33, MX34, MX35, MX36, MX37, MX38, MX39: MX-NoLED; SW_Cherry_MX_1.00u_PCB_perso
MX2: MX-NoLED; SW_Cherry_MX_1.50u_PCB_perso
MX4, MX42: MX-NoLED; SW_Cherry_MX_1.25u_PCB_perso
MX22: MX-NoLED; MXOnly-6.25U-ReversedStabilizers-NoLED
MX40: MX-NoLED; MXOnly-ISO-ReversedStabilizers-NoLED
MX41: MX-NoLED; SW_Cherry_MX_1.75u_PCB_perso
R1, R2: 22; R_0805_2012Metric_Pad1.20x1.40mm_HandSolder
R3, R4: 10k; R_0805_2012Metric_Pad1.20x1.40mm_HandSolder
R5, R6: 5.1k; R_0805_2012Metric_Pad1.20x1.40mm_HandSolder
SW1: SW_Push; SW_SPST_SKQG_WithStem
U1: ATmega32U4-AU; TQFP-44_10x10mm_P0.8mm
U2: PRTR5V0U2X; SOT143B
USB1: HRO-TYPE-C-31-M-12; HRO-TYPE-C-31-M-12-HandSoldering
Y1: 16MHz; Crystal_SMD_3225-4Pin_3.2x2.5mm_HandSoldering

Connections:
+5V: C1.1, C2.1, C3.1, C6.1, C8.1, F1.1, J1.2 (VCC), R3.1, U1.2 (UVCC), U1.7 (VBUS), U1.14 (VCC), U1.24 (AVCC), U1.34 (VCC), U1.44 (AVCC)
COL0: MX1.1 (COL), MX2.1 (COL), MX3.1 (COL), MX4.1 (COL), U1.28 (PB4)
COL1: MX5.1 (COL), MX6.1 (COL), MX7.1 (COL), MX8.1 (COL), U1.29 (PB5)
COL2: MX9.1 (COL), MX10.1 (COL), MX11.1 (COL), MX12.1 (COL), U1.30 (PB6)
COL3: MX13.1 (COL), MX14.1 (COL), MX15.1 (COL), U1.31 (PC6)
COL4: MX16.1 (COL), MX17.1 (COL), MX18.1 (COL), U1.32 (PC7)
COL5: MX19.1 (COL), MX20.1 (COL), MX21.1 (COL), MX22.1 (COL), U1.37 (PF6)
COL6: MX23.1 (COL), MX24.1 (COL), MX25.1 (COL), U1.36 (PF7)
COL7: MX26.1 (COL), MX27.1 (COL), MX28.1 (COL), U1.8 (PB0)
COL8: MX29.1 (COL), MX30.1 (COL), MX31.1 (COL), U1.19 (PD1)
COL9: MX32.1 (COL), MX33.1 (COL), MX34.1 (COL), MX35.1 (COL), U1.20 (PD2)
COL10: MX36.1 (COL), MX37.1 (COL), MX38.1 (COL), MX39.1 (COL), U1.21 (PD3)
COL11: MX40.1 (COL), MX41.1 (COL), MX42.1 (COL), U1.25 (PD4)
D+: R2.2, U2.2 (IO1), USB1.6 (DP1), USB1.8 (DP2)
D-: R1.2, U2.3 (IO2), USB1.5 (DN2), USB1.7 (DN1)
Earth: FB1.2, USB1.13 (SHIELD)
GND: C1.2, C2.2, C3.2, C4.2, C5.1, C6.2, C7.2, C8.2, FB1.1, J1.6 (GND), R4.2, R5.2, R6.2, SW1.1, U1.5 (UGND), U1.15 (GND), U1.23 (GND), U1.35 (GND), U1.43 (GND), U2.1 (GND), USB1.1 (GND), USB1.12 (GND), Y1.2, Y1.4
MISO: J1.1 (MISO), U1.11 (PB3)
MOSI: J1.4 (MOSI), U1.10 (PB2)
unnamed: C7.1, U1.6 (UCAP)
unnamed: D1.2 (A), MX1.2 (ROW)
unnamed: D2.2 (A), MX2.2 (ROW)
unnamed: D3.2 (A), MX3.2 (ROW)
unnamed: D4.2 (A), MX4.2 (ROW)
unnamed: D5.2 (A), MX5.2 (ROW)
unnamed: D6.2 (A), MX6.2 (ROW)
unnamed: D7.2 (A), MX7.2 (ROW)
unnamed: D8.2 (A), MX8.2 (ROW)
unnamed: D9.2 (A), MX9.2 (ROW)
unnamed: D10.2 (A), MX10.2 (ROW)
unnamed: D11.2 (A), MX11.2 (ROW)
unnamed: D12.2 (A), MX12.2 (ROW)
unnamed: D13.2 (A), MX13.2 (ROW)
unnamed: D14.2 (A), MX14.2 (ROW)
unnamed: D15.2 (A), MX15.2 (ROW)
unnamed: D16.2 (A), MX16.2 (ROW)
unnamed: D17.2 (A), MX17.2 (ROW)
unnamed: D18.2 (A), MX18.2 (ROW)
unnamed: D19.2 (A), MX19.2 (ROW)
unnamed: D20.2 (A), MX20.2 (ROW)
unnamed: D21.2 (A), MX21.2 (ROW)
unnamed: D22.2 (A), MX22.2 (ROW)
unnamed: D23.2 (A), MX23.2 (ROW)
unnamed: D24.2 (A), MX24.2 (ROW)
unnamed: D25.2 (A), MX25.2 (ROW)
unnamed: D26.2 (A), MX26.2 (ROW)
unnamed: D27.2 (A), MX27.2 (ROW)
unnamed: D28.2 (A), MX28.2 (ROW)
unnamed: D29.2 (A), MX29.2 (ROW)
unnamed: D30.2 (A), MX30.2 (ROW)
unnamed: D31.2 (A), MX31.2 (ROW)
unnamed: D32.2 (A), MX32.2 (ROW)
unnamed: D33.2 (A), MX33.2 (ROW)
unnamed: D34.2 (A), MX34.2 (ROW)
unnamed: D35.2 (A), MX35.2 (ROW)
unnamed: D36.2 (A), MX36.2 (ROW)
unnamed: D37.2 (A), MX37.2 (ROW)
unnamed: D38.2 (A), MX38.2 (ROW)
unnamed: D39.2 (A), MX39.2 (ROW)
unnamed: D40.2 (A), MX40.2 (ROW)
unnamed: D41.2 (A), MX41.2 (ROW)
unnamed: D42.2 (A), MX42.2 (ROW)
unnamed: R1.1, U1.3 (D-)
unnamed: R2.1, U1.4 (D+)
unnamed: R4.1, U1.33 (~HWB~/PE2)
unnamed: R5.1, USB1.10 (CC2)
unnamed: R6.1, USB1.4 (CC1)
RESET: J1.5 (~RST), R3.2, SW1.2, U1.13 (~RESET)
ROW0: D1.1 (K), D5.1 (K), D9.1 (K), D13.1 (K), D16.1 (K), D19.1 (K), D23.1 (K), D26.1 (K), D29.1 (K), D32.1 (K), D36.1 (K), D40.1 (K), U1.1 (PE6)
ROW1: D2.1 (K), D6.1 (K), D10.1 (K), D14.1 (K), D17.1 (K), D20.1 (K), D24.1 (K), D27.1 (K), D30.1 (K), D33.1 (K), D37.1 (K), U1.38 (PF5)
ROW2: D3.1 (K), D7.1 (K), D11.1 (K), D15.1 (K), D18.1 (K), D21.1 (K), D25.1 (K), D28.1 (K), D31.1 (K), D34.1 (K), D38.1 (K), D41.1 (K), U1.41 (PF0)
ROW3: D4.1 (K), D8.1 (K), D12.1 (K), D22.1 (K), D35.1 (K), D39.1 (K), D42.1 (K), U1.40 (PF1)
SCK: J1.3 (SCK), U1.9 (PB1)
VCC: F1.2, U2.4 (VCC), USB1.2 (VBUS), USB1.11 (VBUS)
XTAL1: C4.1, U1.17 (XTAL1), Y1.1
XTAL2: C5.2, U1.16 (XTAL2), Y1.3

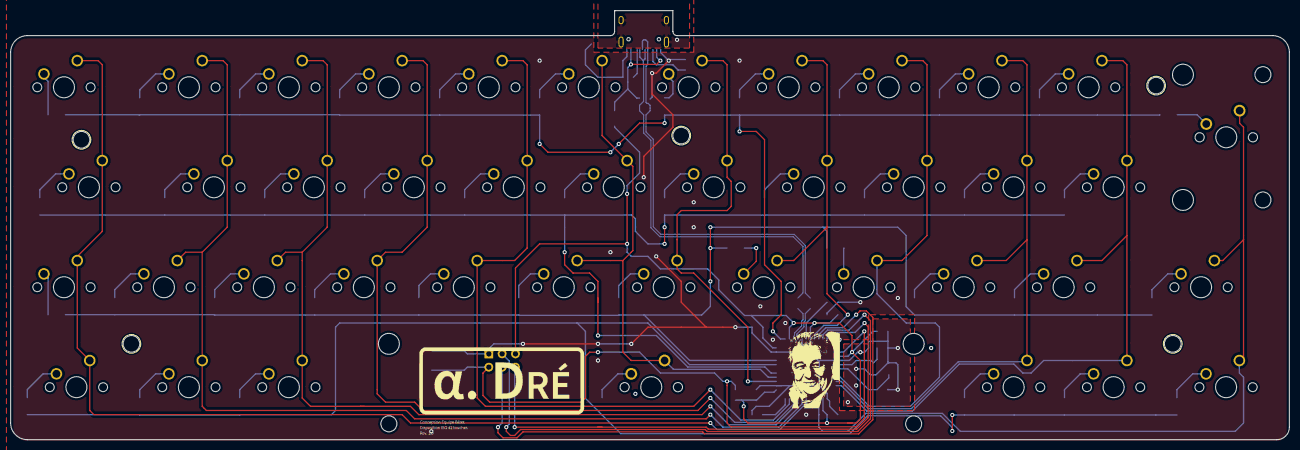
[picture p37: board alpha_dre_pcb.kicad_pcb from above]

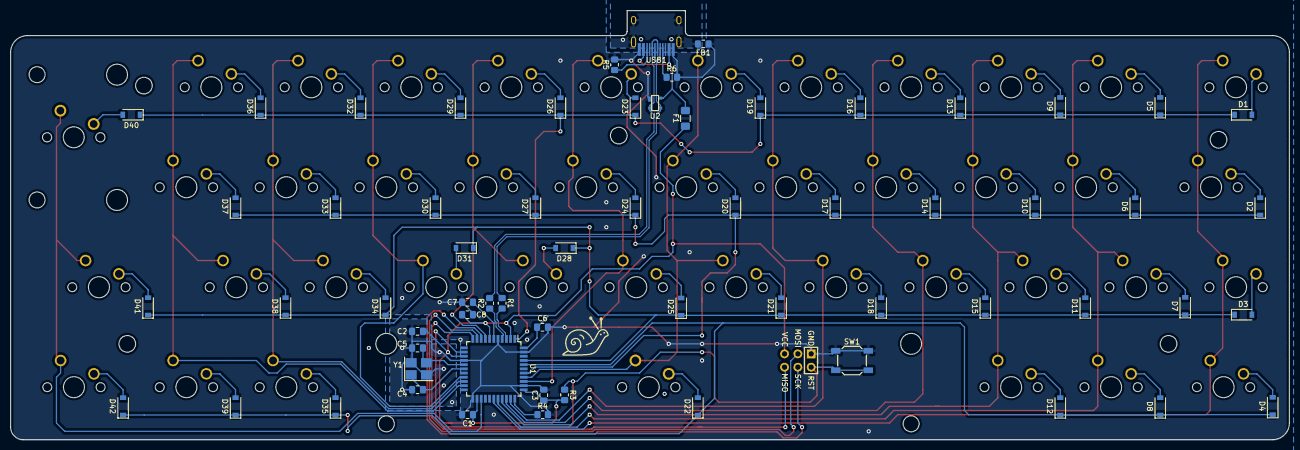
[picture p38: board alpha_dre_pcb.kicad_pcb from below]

Board: 2 copper layers, 243.7 x 81.8 mm, 109 parts (65 on the bottom side), 76 nets.

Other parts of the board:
Ref**: Val**; escargot_design
Ref**#2: Val**; info_design
Ref**#3: Val**; alpha_dre_design

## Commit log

2021-04-16 Initial commit
    Migration from gitlab to github.
    Private repo at the moment
    Rename the project Alpha Dré
    [isio42_pcb.csv, isio42_pcb.kicad_pcb, isio42_pcb.sch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]
2021-04-16 Add gerbers
    Add gerbers to manufacture the PCB
    Add aknowlegment to the readme file
    [isio42_pcb-B_Cu.gbr, isio42_pcb-B_Mask.gbr, isio42_pcb-B_SilkS.gbr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]
2021-04-17 Update renders
    Add holes for the tray mounted version (update gerbers)
    Add new rends with precise dimensions
    [angle_support.stl, bottom.dxf, bottom.stl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]
2021-04-17 Add readme file for case conception
2021-04-17 Added gerbers and renders
    [alpha_dre_pcb.csv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]
2021-04-18 Add trechnical drawings for case fabrication
    Add snail drawing for PCB
    [case_bottom_line.dxf, case_foot_line.dxf, case_foot_option_line.dxf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]
2021-04-18 Add alpha dre ai design for pcb
2021-04-18 Add information design for PCB
2021-04-18 Update case files, pcb drawings
    [case_bottom_alone_line.dxf, case_bottom_line.dxf, case_circ_stand_line.dxf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]
2021-04-18 Final changes before ordering acrylic plates
2021-04-18 Clean kicad project
    [alpha_dre_pcb.csv, alpha_dre_pcb.kicad_pcb, alpha_dre_pcb.sch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]
2021-04-18 Change pcb color to dark
2021-05-10 Add BOM for soldering
    [alpha_dre_pcb_bom.csv, alpha_dre_pcb_bom_excel.xlsx]
2021-05-13 Update multiple readme to present prototype results
    Change the render folder to move it in the docs folder
    Add the firmware folder with the .hex files to flash the keyboard and work on the keymaps
    Add the pictures made with the prototype
2021-05-26 Add Via + Vial compat
    Change a bit the outline of the readme to give more space to the practical information and put the nice pictures and renders at the end of the document.
    Update Readme with last set of pictures made on the acrylic case.
    Add Via + Vial compat
    TBD info.json in firmware folder
2021-06-06 Rework one the case
    Rev 2 case with tighter space between caps and case
    Start the conception of 3D printed case (integrated)
    [acry_assembly.SLDASM, alpha_dre_pcb.kicad_pcb, alpha_dre_pcb.sch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]
2021-06-29 Add 3D printed case version and clean folders for concerning the case
    [alpha_dre_pcb.kicad_pcb, angle_support.stl, bottom.stl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]
